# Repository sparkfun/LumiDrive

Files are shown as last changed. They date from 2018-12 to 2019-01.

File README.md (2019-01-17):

SparkFun LumiDrive LED Driver 
========================================

SparkFun LumiDrive LED Driver

[*SparkFun LumiDrive LED Driver (14779)*](https://www.sparkfun.com/products/14779)

The LumiDrive LED Driver is SparkFun’s foray into all things Python on micro-controllers. With the SparkFun LumiDrive you will be able to control and personalize a whole strand of APA102s directly from the board itself. We’ve broken out a number of analog and digital pins from the on board SAMD21G-AU microcontroller to incorporate your own external buttons, switches, and other interfaces to interact with your addressable LED strip.

It feels like Arduino, but without the need to upload and compile code. Because the LumiDrive opens up like a USB drive on your computer when you plug it in and the code you write lives directly inside the drive it feels very much like an Arduino-device. The fact that you don’t need to upload and compile code makes it a great transitionary LED driver from your traditional Arduino!

The SparkFun LumiDrive has been equipped with a USB-C connector which is capable enough to supply up to 1.5 Amps from a 3.1 USB port, a LiPo connector and charge circuit for portable power, as well as two poke-home connectors to allow you to plug in wires without the need for solder.

Repository Contents
-------------------

* **/Buzzard Labels** - Silkscreen Libraries for Eagle Files
* **/Hardware** - Eagle design files (.brd, .sch)

Documentation
--------------
* **[Hookup Guide](https://learn.sparkfun.com/tutorials/lumidrive-hookup-guide)** - Basic hookup guide for the LumiDrive LED Driver.
* **[Example Code](https://github.com/sparkfun/SparkFun_LumiDrive_Example_Code)** - Example Code for the LumiDrive LED Driver.

License Information
-------------------

This product is _**open source**_! 

Please review the LICENSE.md file for license information. 

If you have any questions or concerns on licensing, please contact techsupport@sparkfun.com.

Distributed as-is; no warranty is given.

- Your friends at SparkFun.

_<COLLABORATION CREDIT>_

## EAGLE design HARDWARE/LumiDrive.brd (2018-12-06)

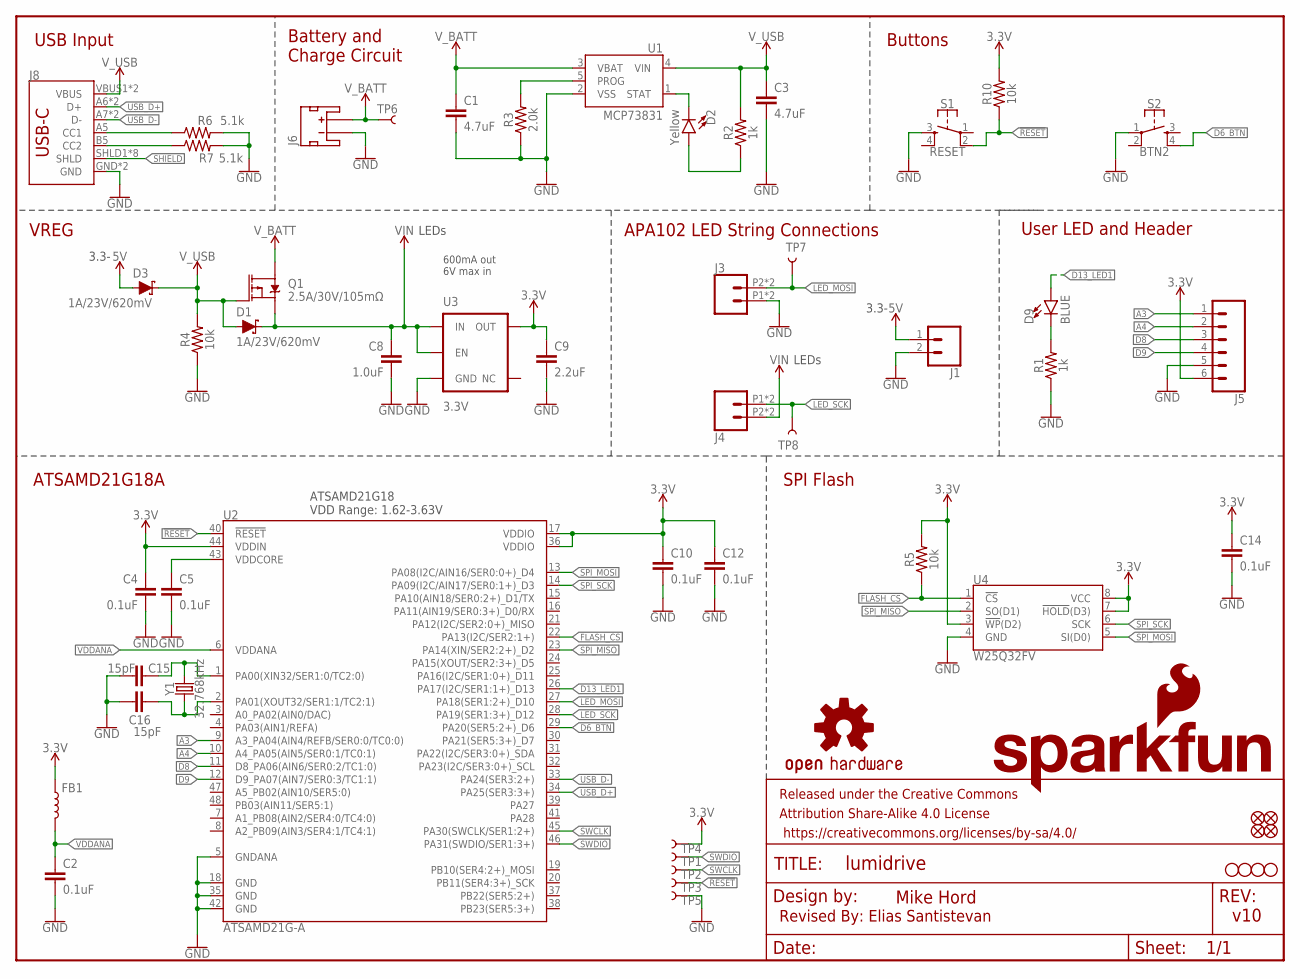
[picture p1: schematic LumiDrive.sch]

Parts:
C1, C3: 4.7uF; 0603
C2, C4, C5, C10, C12, C14: 0.1uF; 0603
C8: 1.0uF; 0805
C9: 2.2uF; 0603
C15, C16: 15pF; 0603
D1, D3: 1A/23V/620mV; SOD-323
D2: Yellow; LED-0603
D9: BLUE; LED-0603
FB1: 30Ω/1.8A; 0603
FD1, FD2, FD3, FD4: FIDUCIALUFIDUCIAL; FIDUCIAL-MICRO
FRAME1: FRAME-LETTER; CREATIVE_COMMONS
H1, H2, H3, H4: STAND-OFF
J1: CONN_021X02_NO_SILK; 1X02_NO_SILK
J3, J4: CONN_02SMALL_POKEHOME; 1X02_POKEHOME
J5: CONN_06NO_SILK_FEMALE_PTH; 1X06_NO_SILK
J6: JST_2MM_MALE; JST-2-SMD
J8: USB_C16PIN; USB-C-16P
LOGO1: OSHW-LOGOM; OSHW-LOGO-M
LOGO3: SFE_LOGO_NAME_FLAME.2_INCH; SFE_LOGO_NAME_FLAME_.2
Q1: 2.5A/30V/105mΩ; SOT23-3
R1, R2: 1k; 0603
R3: 2.0k; 0603
R4, R5, R10: 10k; 0603
R6, R7: 5.1k; 0603
S1: RESET; TACTILE_SWITCH_SMD_4.6X2.8MM
S2: BTN2; TACTILE_SWITCH_SMD_4.6X2.8MM
TP1: TP-SWDIO; PAD.03X.05
TP2: TP-SWCLK; PAD.03X.05
TP3: TP-!RESET!; PAD.03X.05
TP4: TP-3.3V; PAD.03X.05
TP5: TP-GND; PAD.03X.05
TP6, TP7, TP8: TEST-POINT3X4; PAD.03X.04
U1: MCP73831; SOT23-5
U2: ATSAMD21G-A; TQFP-48
U3: 3.3V; SOT23-5
U4: W25Q32FV; SOIC-8
Y1: 32.768kHz; CRYSTAL-SMD-3.2X1.5MM

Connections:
3.3V: C4.1, C9.1, C10.1, C12.1, C14.1, FB1.1, J5.6, R5.2, R10.2, TP4.P$1, U2.17 (VDDIO), U2.36 (VDDIO), U2.44 (VDDIN), U3.5 (OUT), U4.3 (!WP!(D2)), U4.7 (!HOLD!(D3)), U4.8 (VCC)
5V: D3.A, J1.1
!RESET: R10.1, S1.2, TP3.P$1, U2.40 (!RESET!)
A3: J5.1, U2.9 (A3_PA04(AIN4/REFB/SER0:0/TC0:0))
A4: J5.2, U2.10 (A4_PA05(AIN5/SER0:1/TC0:1))
D6_BTN: S2.4, U2.29 (PA20(SER5:2+)_D6)
D8: J5.3, U2.11 (D8_PA06(AIN6/SER0:2/TC1:0))
D9: J5.4, U2.12 (D9_PA07(AIN7/SER0:3/TC1:1))
D13_LED1: D9.A, U2.26 (PA17(I2C/SER1:1+)_D13)
FLASH_CS: R5.1, U2.22 (PA13(I2C/SER2:1+)), U4.1 (!CS!)
GND: C1.2, C2.2, C3.2, C4.2, C5.2, C8.2, C9.2, C10.2, C12.2, C14.2, C15.1, C16.1, J1.2, J3.P1 (1), J3.P3 (1), J5.5, J6.1 (-), J8.GND, J8.GND2 (GND), R1.1, R3.1, R4.1, R6.2, R7.2, S1.3, S2.1, TP5.P$1, U1.2 (VSS), U2.5 (GNDANA), U2.18 (GND), U2.35 (GND), U2.42 (GND), U3.2 (GND), U4.4 (GND)
LED_MOSI: J3.P2 (2), J3.P4 (2), TP7.P$1, U2.27 (PA18(SER1:2+)_D10)
LED_SCK: J4.P1 (1), J4.P3 (1), TP8.P$1, U2.28 (PA19(SER1:3+)_D12)
unnamed: D9.C, R1.2
unnamed: C15.2, U2.1 (PA00(XIN32/SER1:0/TC2:0)), Y1.P$2 (2)
unnamed: C16.2, U2.2 (PA01(XOUT32/SER1:1/TC2:1)), Y1.P$1 (1)
unnamed: D2.A, R2.1
unnamed: J8.B5 (CC2), R7.1
unnamed: J8.A5 (CC1), R6.1
unnamed: D2.C, U1.1 (STAT)
unnamed: R3.2, U1.5 (PROG)
SHIELD: J8.SHLD1 (SHLD), J8.SHLD2 (SHLD), J8.SHLD3 (SHLD), J8.SHLD4 (SHLD), J8.SHLD5 (SHLD), J8.SHLD6 (SHLD), J8.SHLD7 (SHLD), J8.SHLD8 (SHLD)
SPI_MISO: U2.23 (PA14(XIN/SER2:2+)_D2), U4.2 (SO(D1))
SPI_MOSI: U2.13 (PA08(I2C/AIN16/SER0:0+)_D4), U4.5 (SI(D0))
SPI_SCK: U2.14 (PA09(I2C/AIN17/SER0:1+)_D3), U4.6 (SCK)
SWCLK: TP2.P$1, U2.45 (PA30(SWCLK/SER1:2+))
SWDIO: TP1.P$1, U2.46 (PA31(SWDIO/SER1:3+))
USB_D+: J8.A6 (D+), J8.B6 (D+), U2.34 (PA25(SER3:3+))
USB_D-: J8.A7 (D-), J8.B7 (D-), U2.33 (PA24(SER3:2+))
VDDANA: C2.1, FB1.2, U2.6 (VDDANA)
VDDCORE: C5.1, U2.43 (VDDCORE)
VIN: C8.1, D1.C, J4.P2 (2), J4.P4 (2), Q1.2 (S), U3.1 (IN), U3.3 (EN)
V_BATT: C1.1, J6.2 (+), Q1.3 (D), TP6.P$1, U1.3 (VBAT)
V_USB: C3.1, D1.A, D3.C, J8.VBUS1 (VBUS), J8.VBUS2 (VBUS), Q1.1 (G), R2.2, R4.2, U1.4 (VIN)

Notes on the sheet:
600mA out 6V max in
v10
Mike Hord
ATSAMD21G18 VDD Range: 1.62-3.63V
USB Input
Buttons
SPI Flash
ATSAMD21G18A
User LED and Header
VREG
APA102 LED String Connections
Battery and Charge Circuit
Revised By: Elias Santistevan
3.3-
LEDs

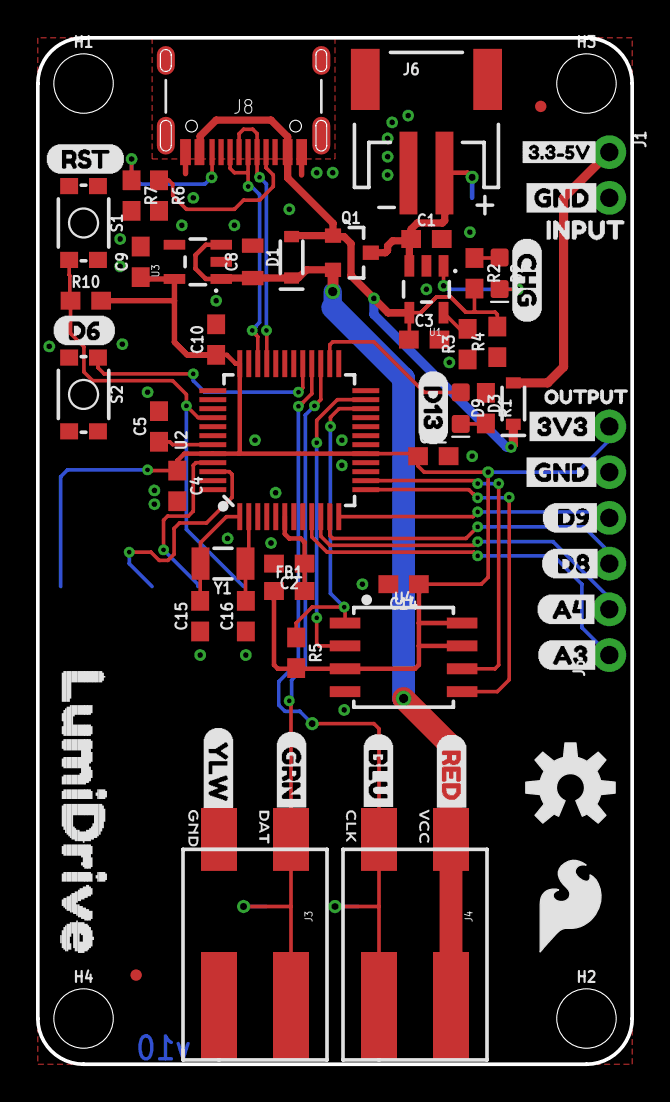
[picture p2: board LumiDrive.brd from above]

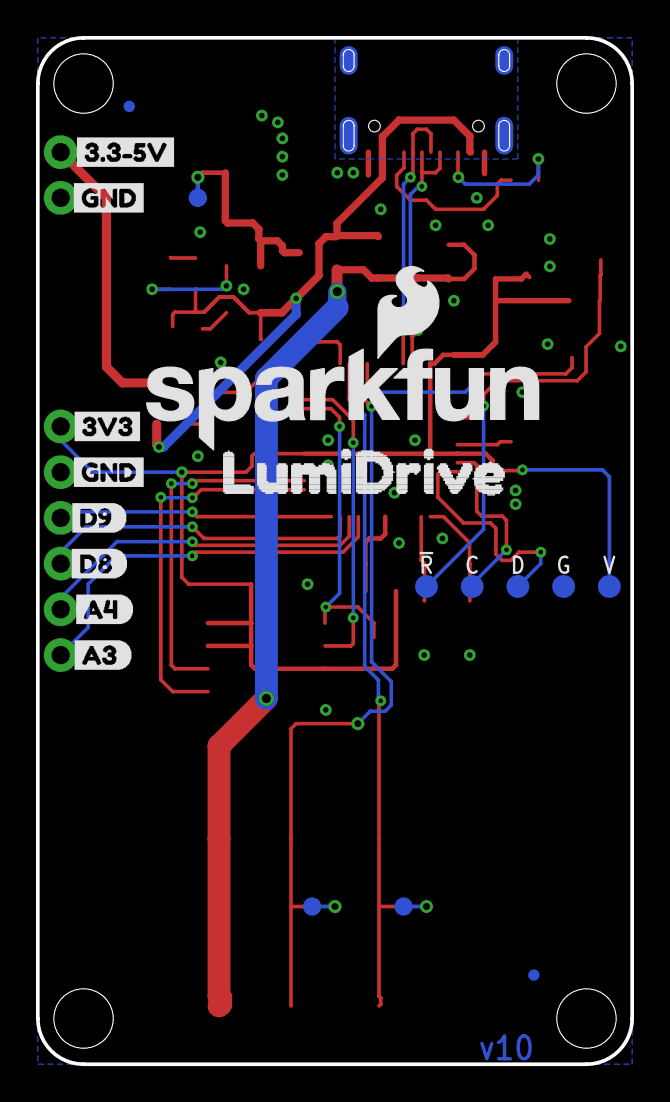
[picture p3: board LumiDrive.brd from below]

Board: 2 copper layers, 33.0 x 57.0 mm, 91 parts (20 on the bottom side), 34 nets.

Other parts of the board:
U$1, U$5, U$19, U$26: GND-04
U$2: GRN0
U$3: BLU0
U$4: YLW0
U$6, U$41: LUMIDRIVE0
U$8, U$29: 3#3#5V0
U$9: INPUT0
U$10: RED0
U$11: RST0
U$12: D60
U$13: CLK1
U$14: DAT2
U$15: GND0
U$16: VCC3
U$17: CHG0
U$18: D130
U$20, U$27: 3V3-04
U$21, U$40: D90
U$22, U$39: D80
U$23, U$38: A40
U$24, U$37: A30
U$25: OUTPUT0
U$28: SFE_LOGO_FLAME_.2

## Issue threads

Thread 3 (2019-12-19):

Suggested Revision

santaimpersonator, 2019-12-19:
A customer suggested adding cap to reset line to work around "power on" hangups. According to the SAMD21 datasheet, in the "External Reset Circuit" section it is suggested that a ~100pF cap is used.

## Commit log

2018-11-02 Ready for protos round 2 (round 1 for me)
    [LumiDrive.brd, LumiDrive.sch]
2018-11-02 Prototype Gerbers
    [LumiDrive.brd]
2018-12-04 Adds production files and assembly sheet, and fixes swapped lipo connector pads
    [LumiDrive.brd, LumiDrive.sch]
2018-12-04 Adds testpoints to LED SLCK and MOSI lines, extra silk labels for INPUT and OUTPUT .....
    labeling INPUT as 3.3V-5V, deletes old production files
    [LumiDrive.brd, LumiDrive.sch]
2018-12-05 Adds clarifying text to the 5V and VIN power symbol, changes silk from "VIN" to "3.3V-5V" , and localizes the "OUTPUT" silk better
    - Changes DRC to tight with approval of the drill hit errors for better clarification on design choices
    [LumiDrive.brd, LumiDrive.sch]
2018-12-06 Moves entire design down .005 mils to X-center
    [LumiDrive.brd]

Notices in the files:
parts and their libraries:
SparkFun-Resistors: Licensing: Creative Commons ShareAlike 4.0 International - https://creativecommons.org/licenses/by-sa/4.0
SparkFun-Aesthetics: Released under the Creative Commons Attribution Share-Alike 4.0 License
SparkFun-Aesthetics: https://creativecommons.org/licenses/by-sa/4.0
